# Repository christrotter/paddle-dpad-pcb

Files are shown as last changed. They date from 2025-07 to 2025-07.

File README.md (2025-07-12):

# paddle-inator
NOTE: Ordered pcbs on July 12, 2025, so this is untested at the moment.

A prototype pcb to mount ALPS SKRHACE010 switches on the back of the thumbcluster and use them as soft-action paddle-keys.  Uses an SK6805-EC15 led indicator and 12-pin 0.5mm pitch FFC connector - I'm trying to move away from single-wire soldering.

The application I'll be trying these out in is for 'curl your fingers inwards' paddle switches, but I needed a very soft touch due to fibromyalgia.

I've been using the SKRHACE010 5-way switches in my dpads and they are wonderful with enough leverage.  I prototyped using an old pcb with that switch and so far seems like this will work just fine.

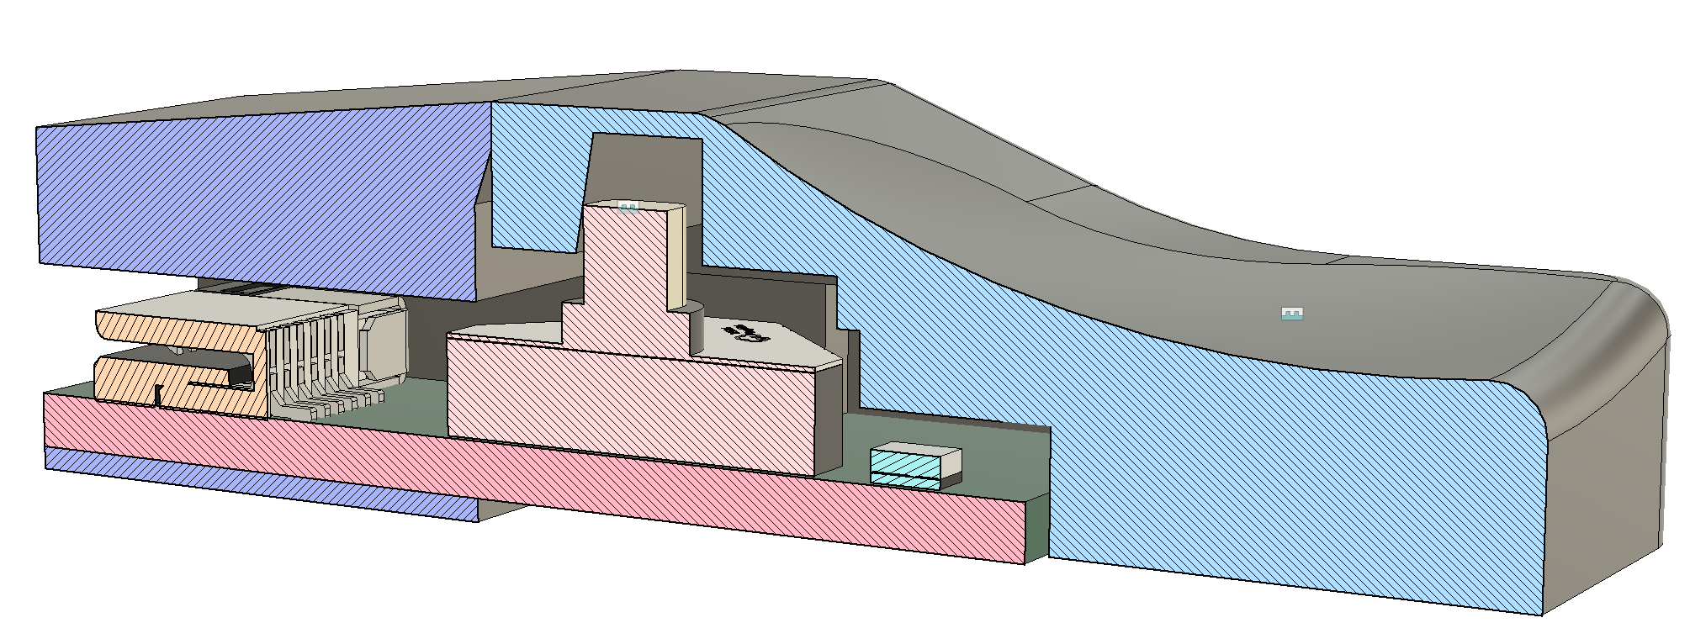
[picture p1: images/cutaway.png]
Cutaway


# Usage example
The actual use case in-model might help to clarify the functionality.  There are three of these paddles just between the thumb keys and main keywell.

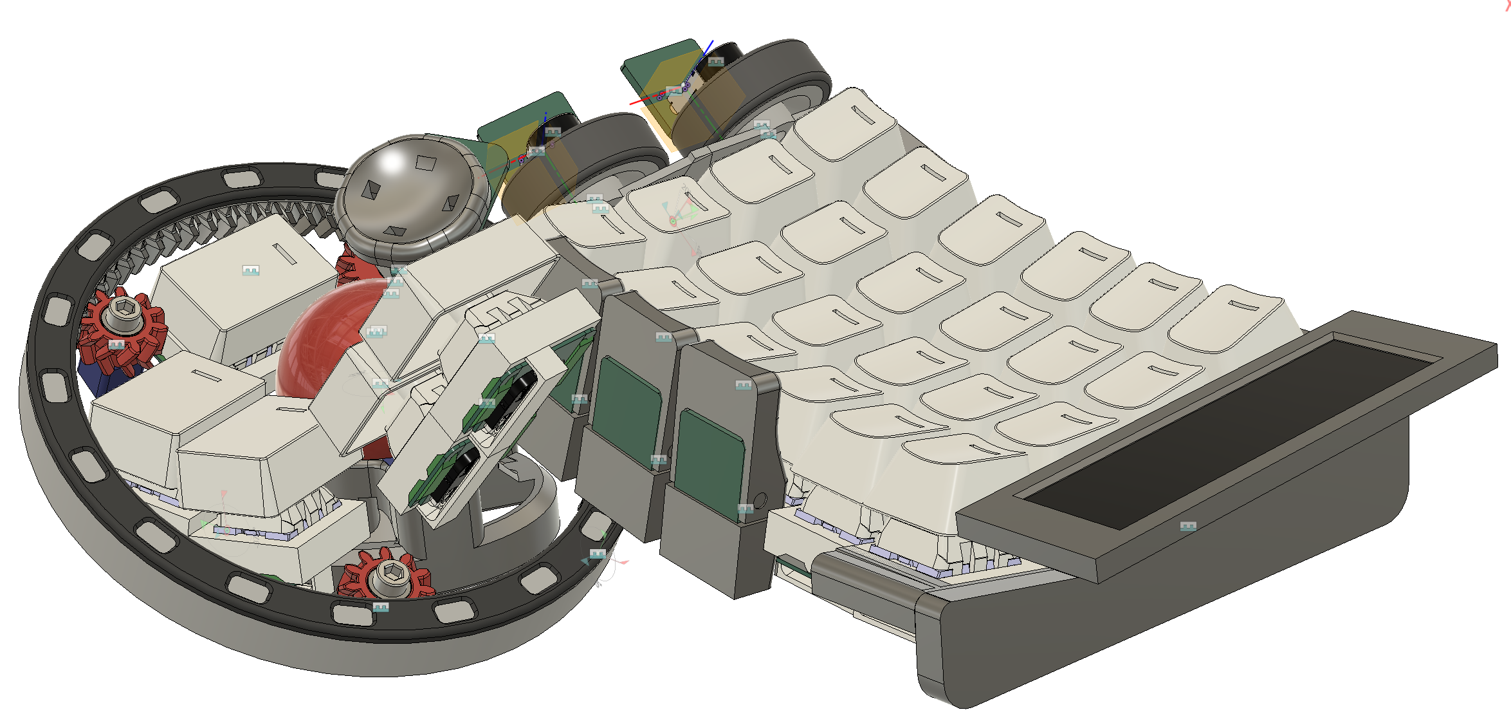
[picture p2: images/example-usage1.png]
Example1

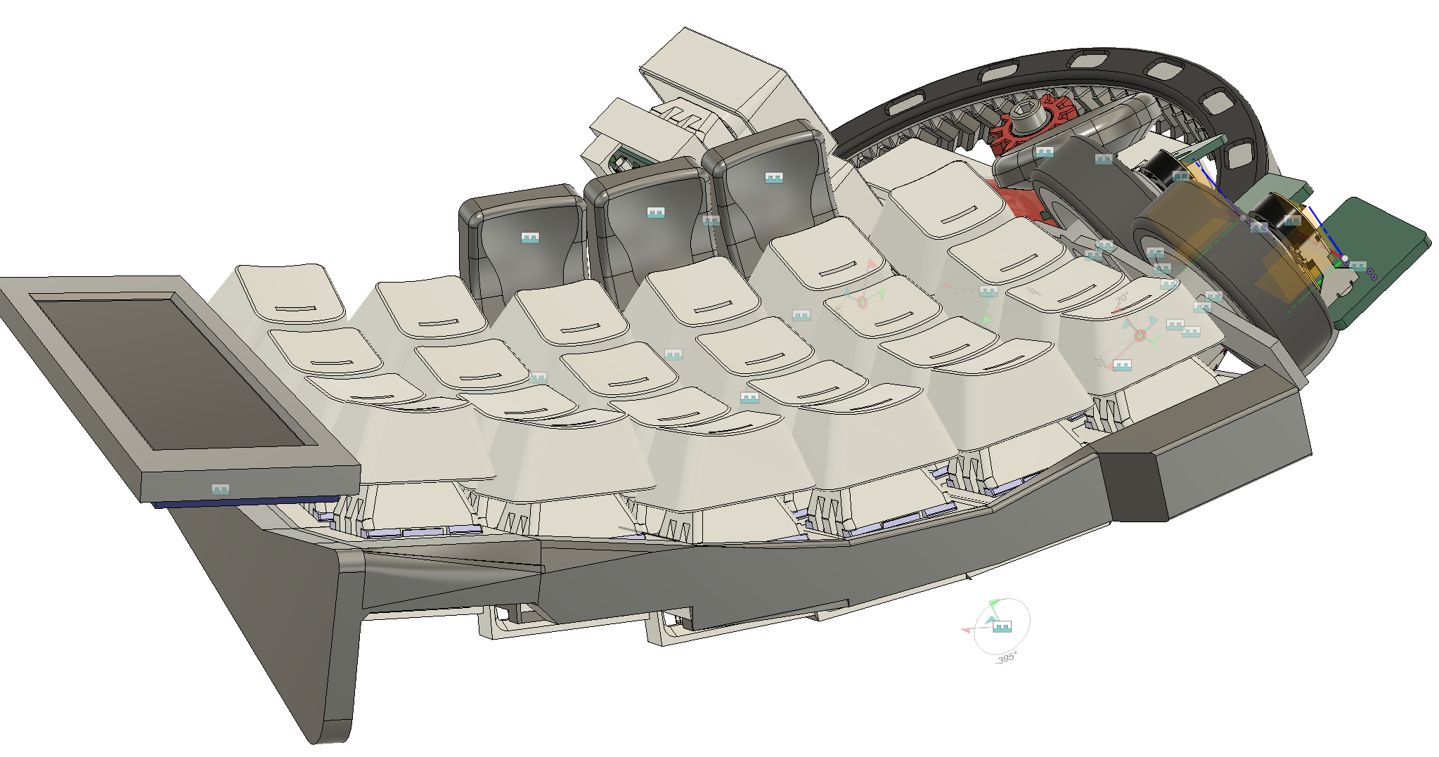
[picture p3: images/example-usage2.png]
Example2


# Connector wiring details
- 3 GND pins, 1 5v pin
- 6 pins for the switch (_even though I only really use one_)
- DI & DO for led signal

# PCB details
- 14.2 x 23.9mm (_why? b/c I wasn't aiming for a specific dimension, just 'small as reasonable'_)
- 1mm radius corners

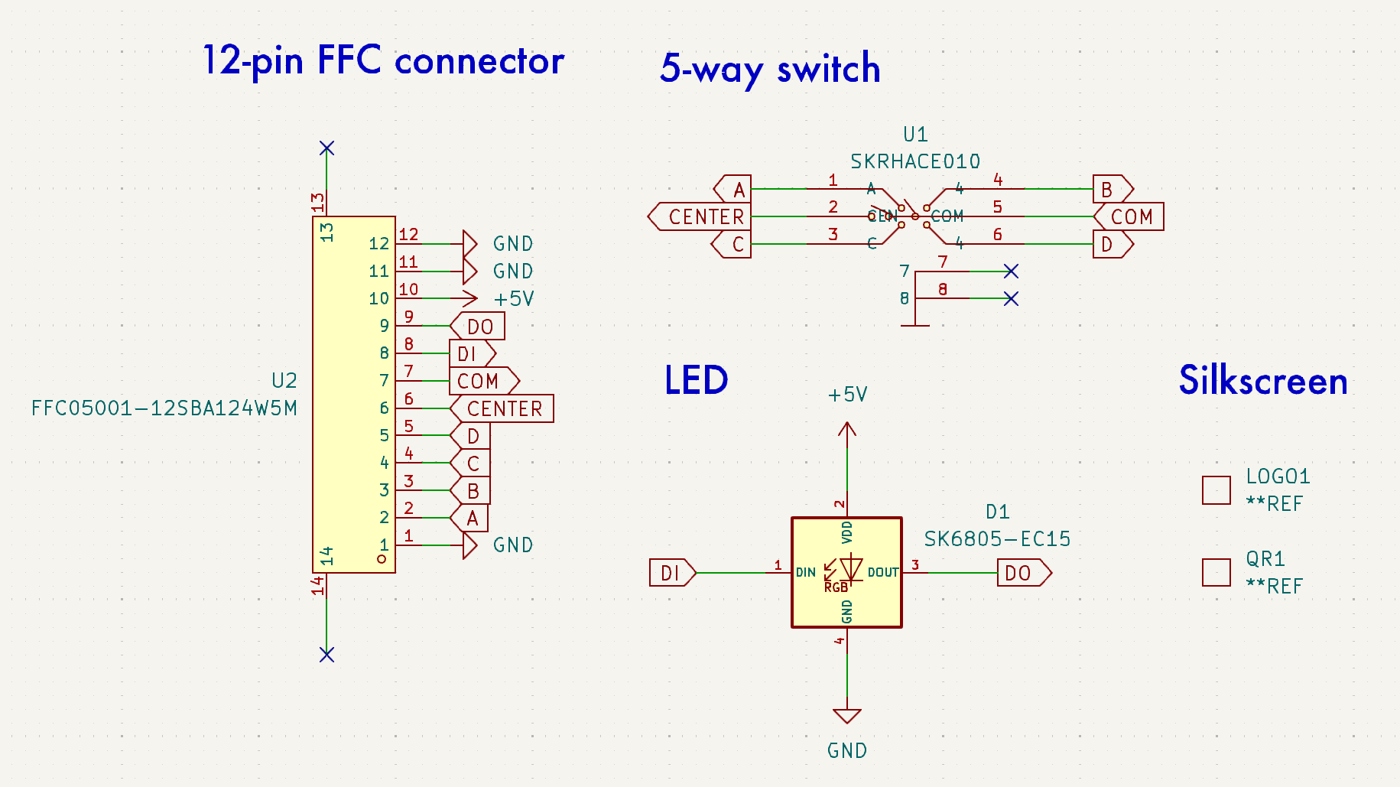
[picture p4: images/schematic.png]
Schematic

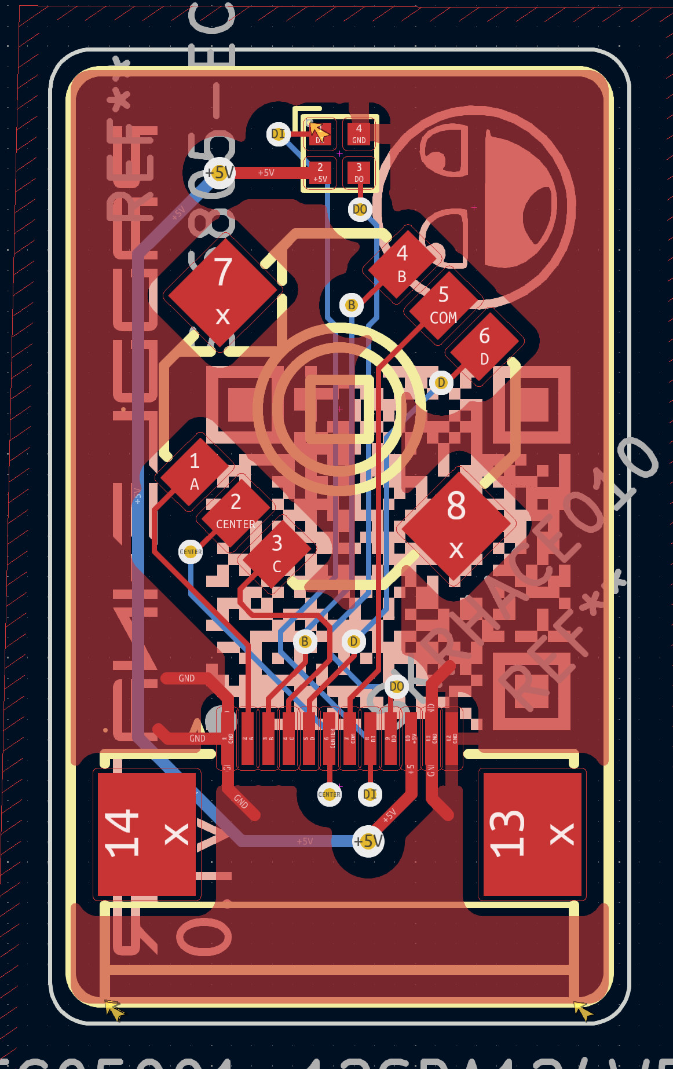
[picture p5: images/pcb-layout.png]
PCB Layout


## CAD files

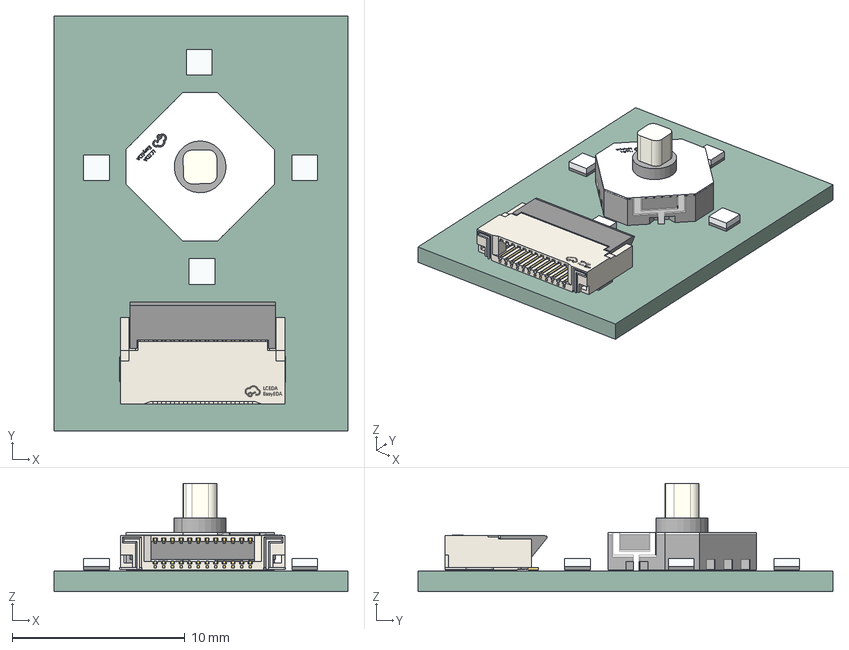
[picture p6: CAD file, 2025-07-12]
paddle-dpad-pcb-v1.step
17.0 x 24.0 x 6.25 mm
SW-SMD_SKRHACE010
LED-SMD_4P-L1.5-W1.5-BL x 4
FFC-SMD_FFC05036-12SBD113W5M
paddle-dpad-pcb_PCB

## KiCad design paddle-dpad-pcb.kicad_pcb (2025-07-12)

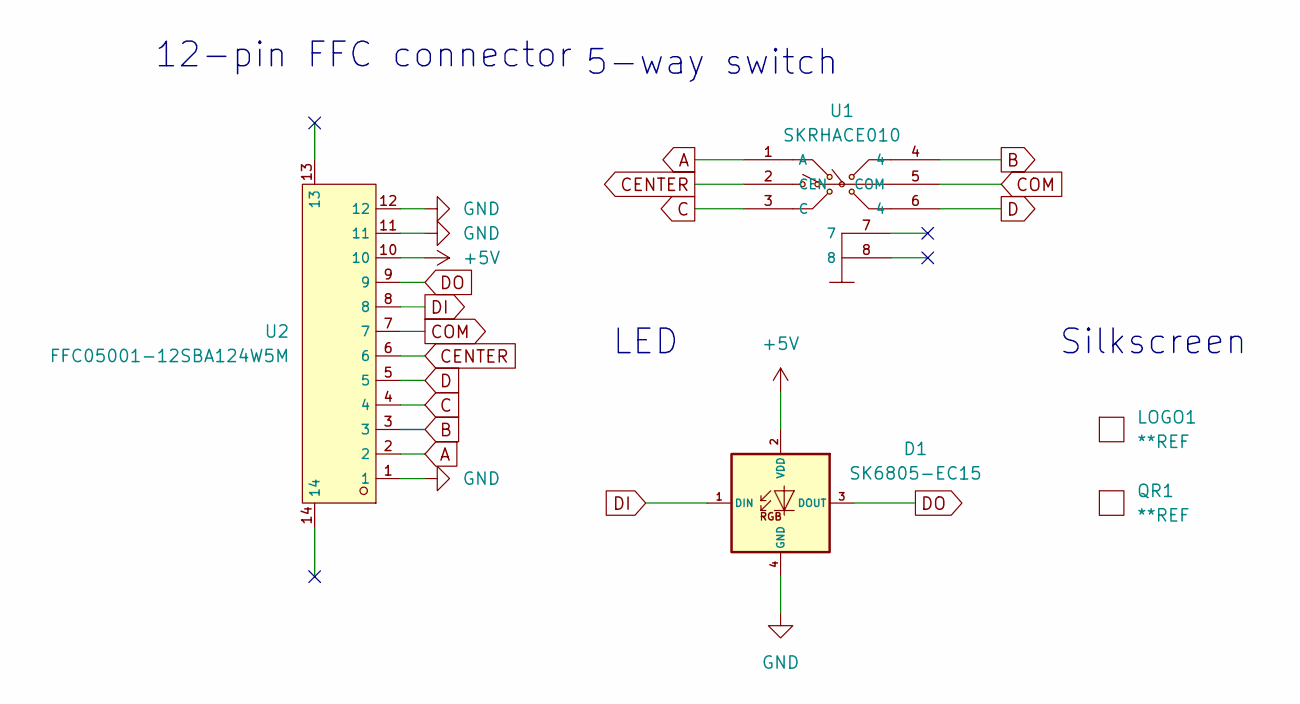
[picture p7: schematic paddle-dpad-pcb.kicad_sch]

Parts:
D1: SK6805-EC15; LED-SMD_4P-L1.5-W1.5-BL; MPN SK6805-EC15; LCSC C2890035
LOGO1: **REF; awesome-logo
QR1: **REF; paddle-dpad-pcb-qr-10mm
U1: SKRHACE010; SW-SMD_SKRHACE010; LCSC C209766
U2: FFC05001-12SBA124W5M; FFC-SMD_FFC05001-12SBA124W5M; LCSC C2833760

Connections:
+5V: D1.2 (VDD), U2.10
A: U1.1 (A), U2.2
B: U1.4, U2.3
C: U1.3 (C), U2.4
CENTER: U1.2 (CEN), U2.6
COM: U1.5 (COM), U2.7
D: U1.6 (4), U2.5
DI: D1.1 (DIN), U2.8
DO: D1.3 (DOUT), U2.9
GND: D1.4 (GND), U2.1, U2.11, U2.12

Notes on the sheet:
12-pin FFC connector
Silkscreen
LED
5-way switch

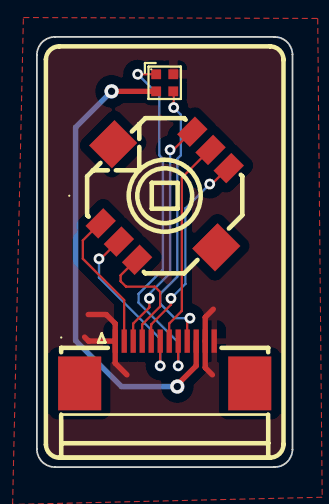
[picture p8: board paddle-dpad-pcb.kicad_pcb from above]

Board: 2 copper layers, 14.2 x 23.9 mm, 5 parts (2 on the bottom side), 10 nets.

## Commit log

2025-07-12 submitted first rev to jlc
    [paddle-dpad-pcb.kicad_pcb, paddle-dpad-pcb.kicad_sch]
2025-07-12 adding step file
    [paddle-dpad-pcb-v1.step]
2025-07-12 minor updates
    [paddle-dpad-pcb.kicad_sch]
